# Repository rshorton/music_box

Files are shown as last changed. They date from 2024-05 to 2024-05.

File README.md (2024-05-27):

# Music Box

This project implements a simple music player using an Arduino and a dedicated mp3 player module.  The motivation was to create a simple nightstand player for my granddaughter.

See this video for a demo of the player:  https://youtu.be/NVYOizomKiI

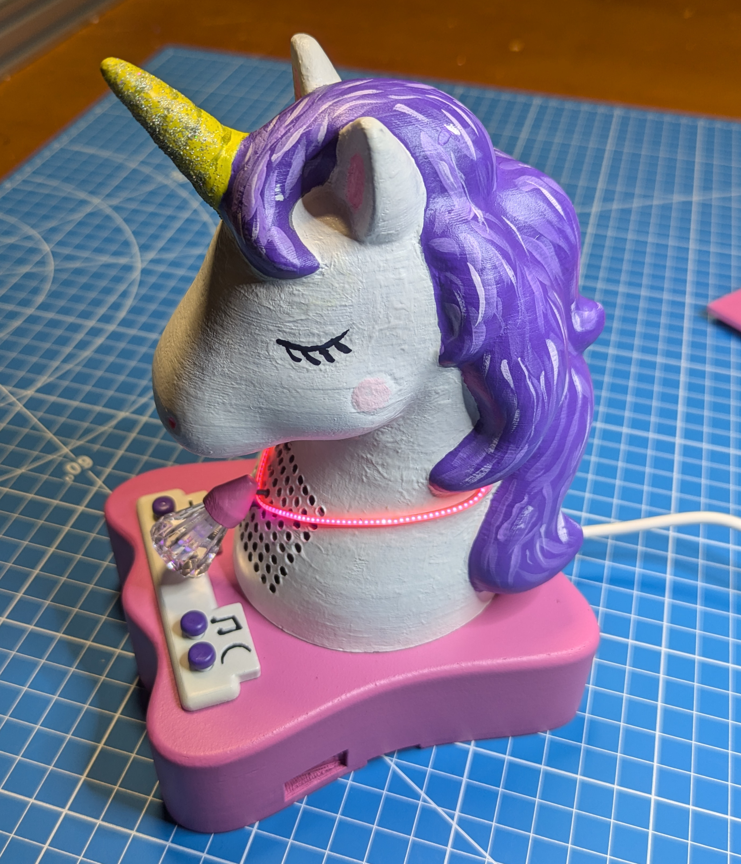
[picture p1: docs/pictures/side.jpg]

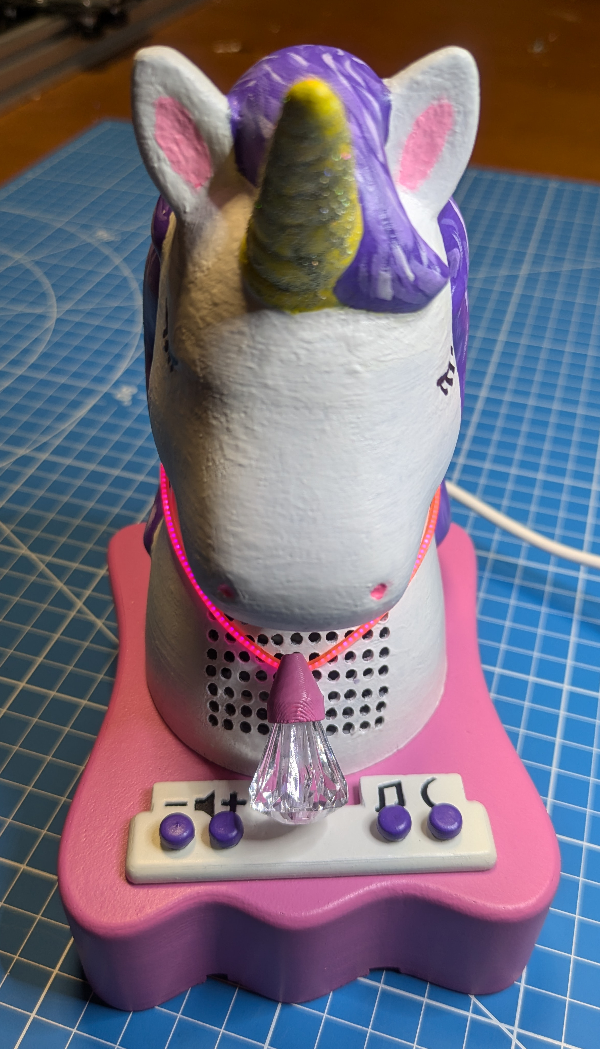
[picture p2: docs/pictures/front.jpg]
<br>
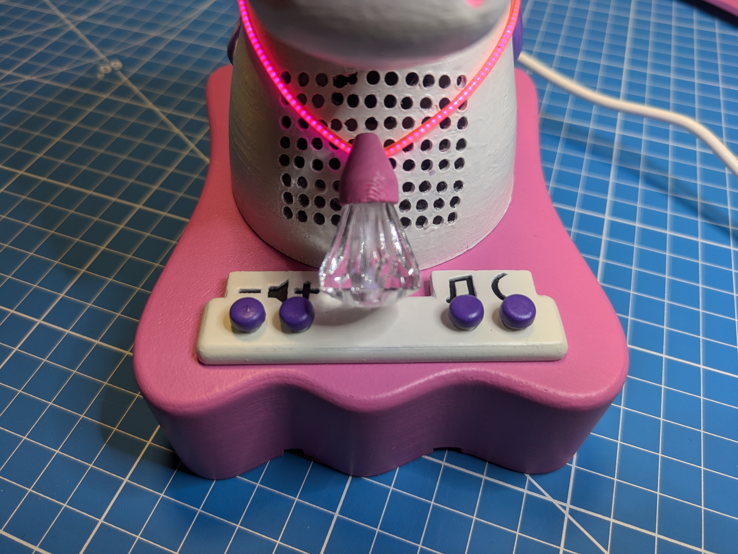
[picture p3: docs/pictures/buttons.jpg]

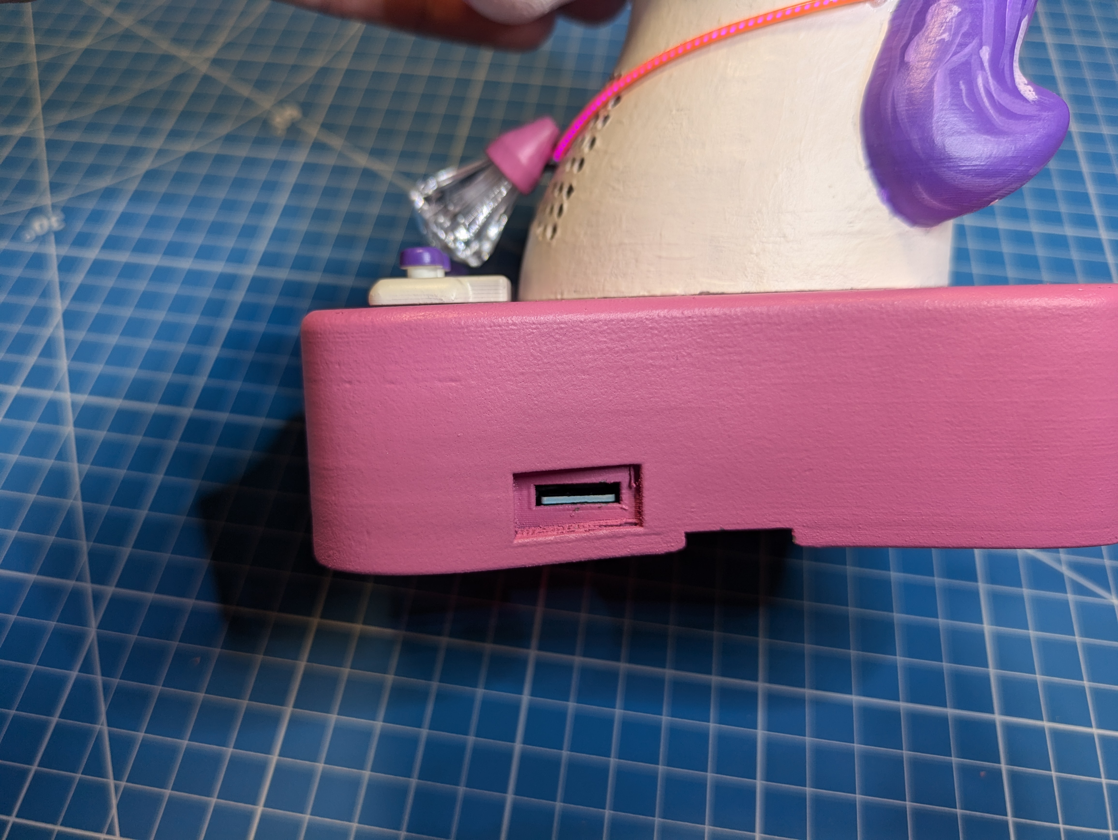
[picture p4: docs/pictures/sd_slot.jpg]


## Circuit

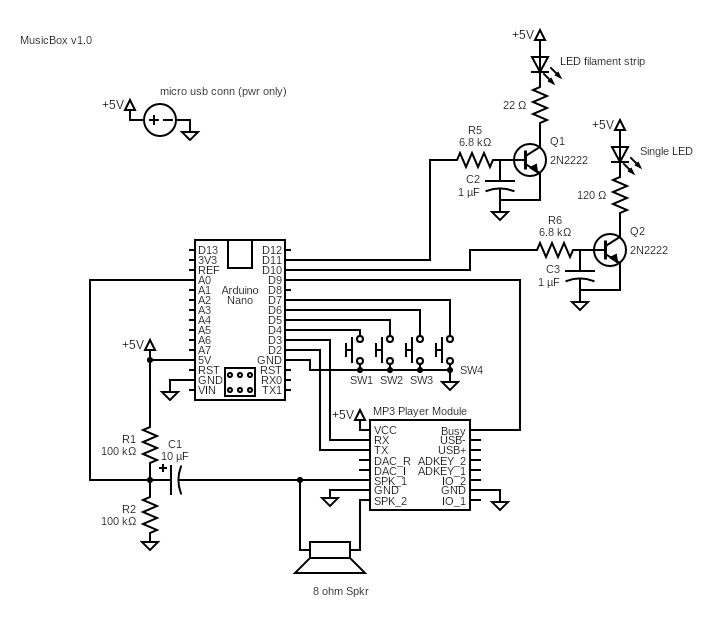
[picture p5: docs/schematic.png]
schematic

<br>
(Drawn using https://www.circuit-diagram.org)

The design uses a dedicated MP3 player module purchased from Amazon for this project plus other on-hand components including an Arduino Nano.  Key functionality:

 * MP3 player module with SD card slot - music is loaded on the SD card (see below).  The program running on the Arduino uses the serial interface of the player to control which mp3 file is played and to control the volume level.  Important: This player module has the same pin-out as the DFPlayer device, but its functionality is not exactly the same.  Credit goes to the various folks who provided an Amazon review of the device and provided clues to using it especially user "Richard Makes Escape Rooms".  The product link is https://www.amazon.com/dp/B07Y2YKYRS?ref=ppx_yo2ov_dt_b_product_details&th=1.  See player.cpp/hpp for the implementation.

 * Arduino Nano - The code of this repo runs on this device.  You could use just about any Arduino or micro for this function.  The program monitors the switch inputs and controls the player module accordingly.  It also flashes the LEDs in either a default 'breathing' mode while not playing where the LED intensity is varied up/down, or flashes based on the audio sound envelope.  Credit to Damian Peckett, https://projecthub.arduino.cc/mamifero/arduino-beat-detector-881c72, for his envelope detector filter that was encapsulated in filter.cpp/hpp.
 
 Other components:

 * 8 ohm 3W 2" speaker
 * Flexible LED filament strip from Adafruit (https://www.adafruit.com/product/5509)
 * Transistor circuits for driving the LEDs
 * Micro-usb adapter for providing power (no signals) to allow a 5v wall wart power supply to be used, https://www.amazon.com/gp/product/B07W844N43/ref=ppx_yo_dt_b_search_asin_title?ie=UTF8&psc=1
 * Reused an old 5v (1A) wall wart supply with micro-usb connector
 * Prototyping PCB board
 * SD card

 

## Software Functionality

Since the music box was designed for a young child, the goal was to make it simple.  As such it uses 4 keys:

* Vol+, Vol-
* One key for music play/next/pause. Press to start playing, short-press to skip to next, and long-press to pause. 
* Message playback - For my implementation these are 'goodnight' messages from the grandparents to our granddaughter.

To add a bit of whimsy, the program also supports some 'easter-egg' audio key-press modes.  Pressing any two-key combination at the same time will play one of several audio clips.  I have it play some silly sound effects such as a cow mooing, fart sound, etc.

For eye candy the LEDs are flashed to the music or in a 'breathing' mode when not playing.

### SD Card Contents

MP3 files for the songs/sound effects where prepared by recording the output of my phone into my laptop using Audacity.  Since the output of the music box is mono and use a small speaker, quality wasn't a goal.  I recorded at the default setting of 44.1kHz and then exported to MP3.

The layout of the audio files is shown below.  Example files are contained in the sample_audio folder of this project that can be use to test.

<hr>

* root directory of SD card
  
  01
  
      This folder contains the music files that are played when the music button is pressed.  
  
  02
  
      This folder contains audio files that are played when then message button (moon symbol) is pressed.  

  03

      This folder contains 'easter-egg' audio files played as described above.
    
<hr>

  Naming convention for audio files

  Number them beginning with 001 for the first file without skipping any numbers.  For example: 
  
      001.mp3   002.mp3 ...   010.mp3
  
  You can optionally append an underscore and then a description such as
  
      001_name of song.mp3

## Enclosure

Since my granddaughter likes unicorns, I chose to use a unicorn as the main design element.  I found a very nice unicorn STL on Thingiverse.

Unicorn Head
by kaloth licensed under the Creative Commons Attribution license.
https://www.thingiverse.com/thing:4920810/files

I printed the unicorn as large as my 3D printer supported and then designed a base using Fusion 360 to support it and hold the PCB for the circuit.

### Design notes

#### Unicorn Head

After printing with PLA, I used a knife and cut out enough material to insert the 2" speaker inside.  I also drilled holes to allow the sound to be better heard (I used a 3D-printed jig for that.).

#### Base

The base has a mounting support for the micro-usb PCB power connector, mounting supports for the main circuit board, and a slot on the side to allow the SD card to be removed after assembly.  I used threaded inserts for mounting the PCBs to the supports.

The top of the base has a slot onto which the button panel inserts.  I chose to use a separately-printed button panel with holes for the buttons since I wasn't sure exactly how many keys were going to be used intially.  That choice also allowed the button function to be designed as a relief in the button panel.  When painting the parts, I tried to paint the relief areas but found it was hard to have clean-looking edges for the resessed areas.  As such, I re-designed the button panel to use cut-outs for the function symbols and resessed areas on the bottom under the symbols where a separately printed piece could be first painted and then inserted to provide the background color.

#### Necklace

The flexible LED strip from Adafruit provides a nice finishing touch to the unicorn.  I also attached a plastic 'jewel' onto the filament.  The jewel has a LED inserted into it.  (The jewel was the initial inspiration for the entire project.)

#### Painting

I'm not an artsy person, so the finishing task was new territory for me.  However, with YouTube by your side you can learn and do almost anything. To smooth out the plastic layers before painting, I used thin layers of 'Bondo glazing & spot putty' and sanded between layers. I used acrylic paint and small brushes for the unicorn head and button tops, and spray paint for most everything else.  I used a clear poly spray coat over everything.

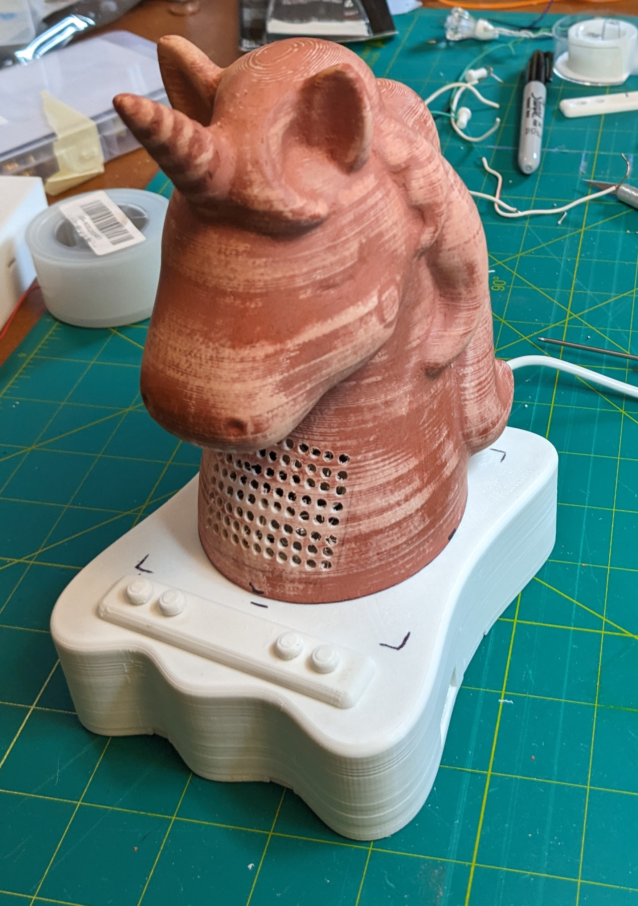
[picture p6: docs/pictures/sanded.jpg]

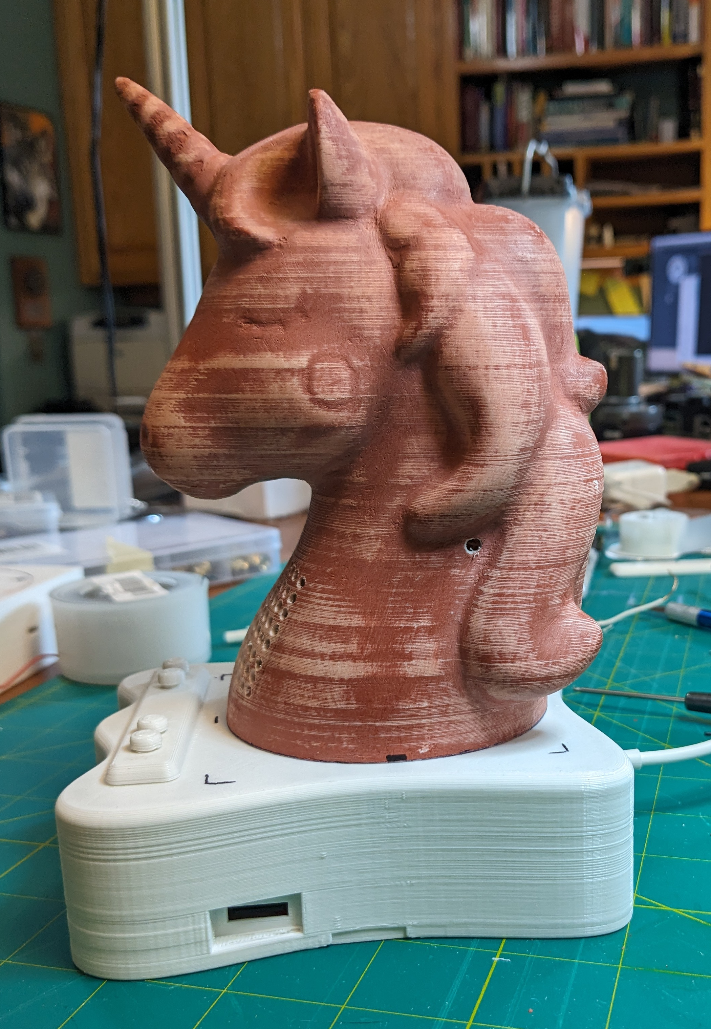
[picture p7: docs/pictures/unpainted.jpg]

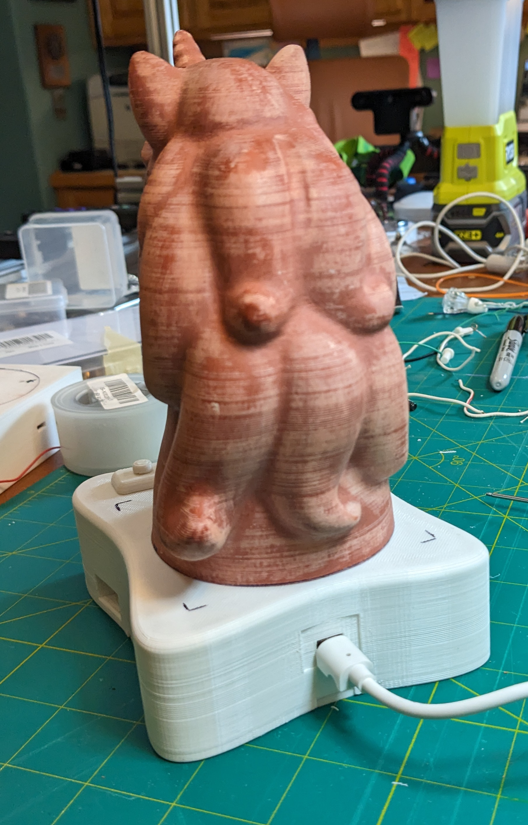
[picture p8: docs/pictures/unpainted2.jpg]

<hr>
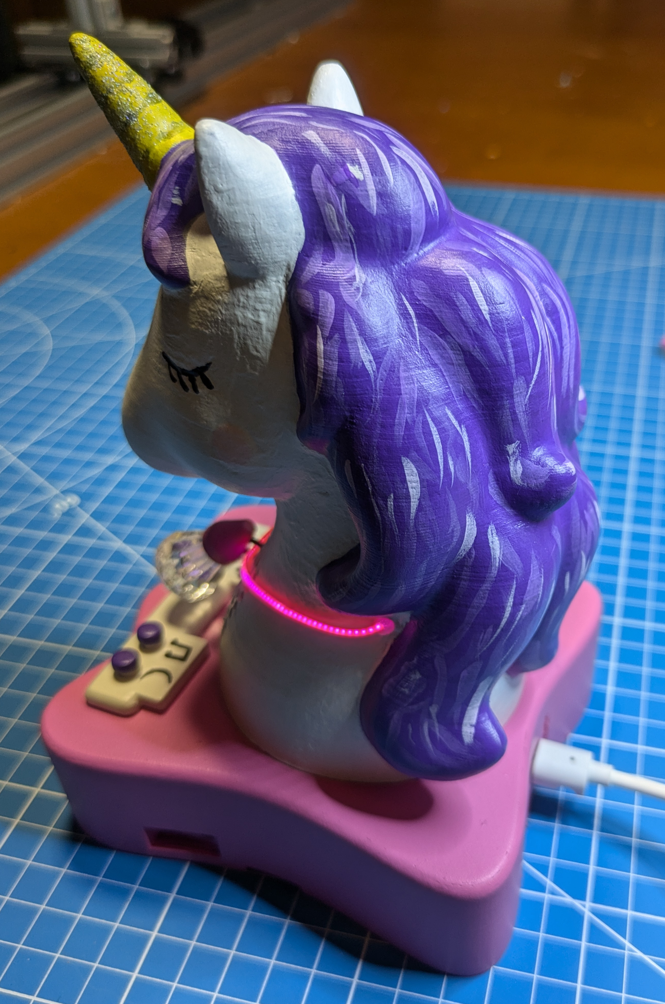
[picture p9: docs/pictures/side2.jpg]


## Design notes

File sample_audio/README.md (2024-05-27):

# Sample audio

The audio in this folder can be used to test the functionality of the music box. Copy the folders contained in this folder to a fat32-formatted SD card.  The contents of the SD card should look like this:

<root directory>
  01

      001.mp3
      002.mp3
      ...
      005.mp3

  02  
  
      001.mp3
      002.mp3
      ...
      005.mp3

  03

      001.mp3
      002.mp3
      ...
      006.mp3

Optionally, if you provide clip 007.mp3 in folder 03, that clip will be played when power is applied to the music box.

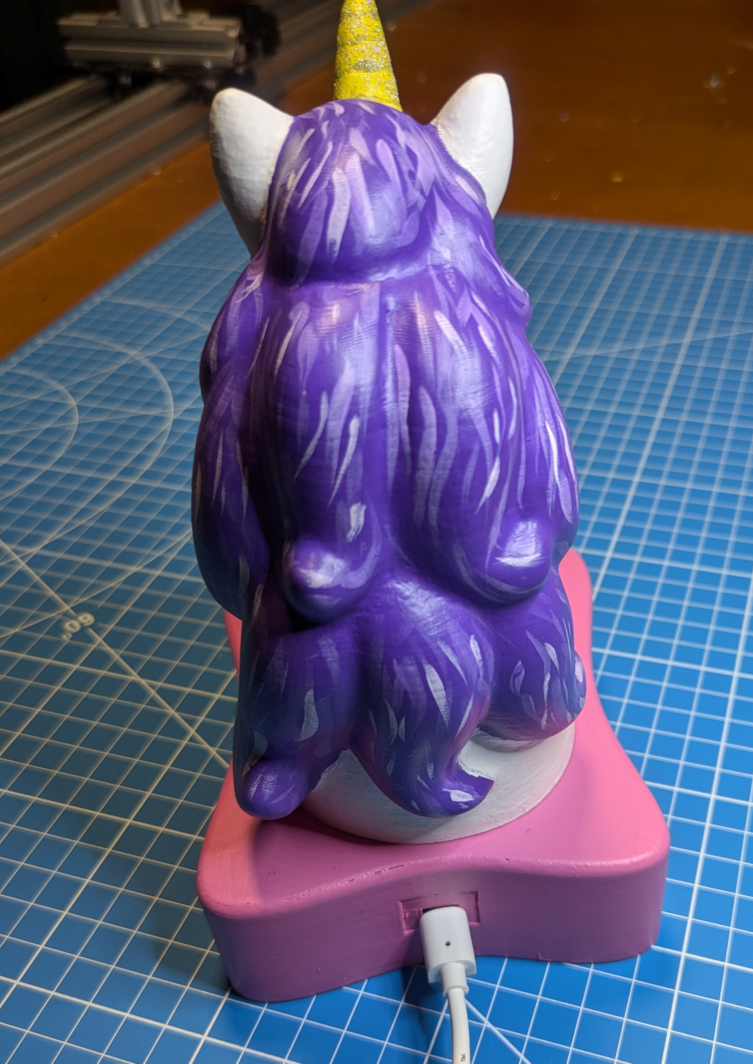
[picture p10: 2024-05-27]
docs/pictures/back.jpg

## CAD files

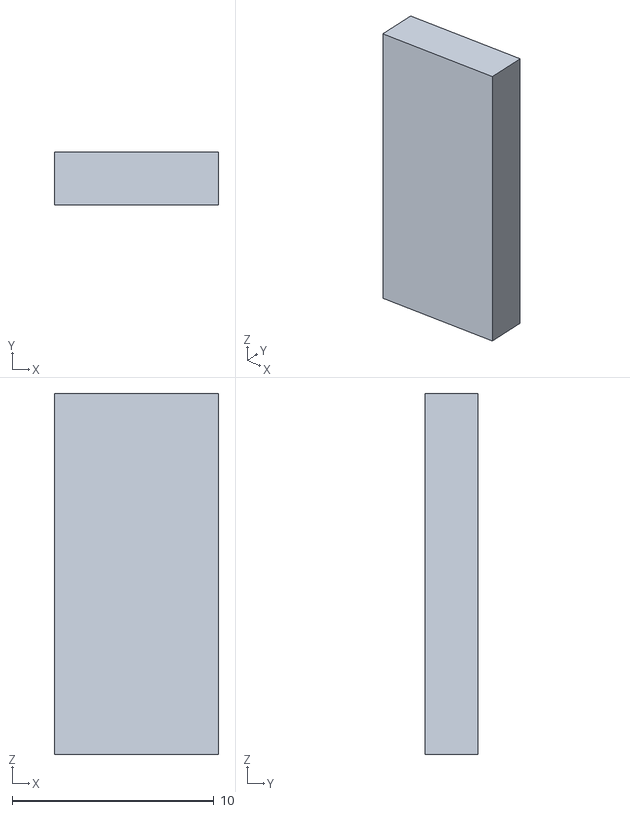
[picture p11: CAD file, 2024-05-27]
stl/filler1.stl
8.15 x 2.65 x 17.9

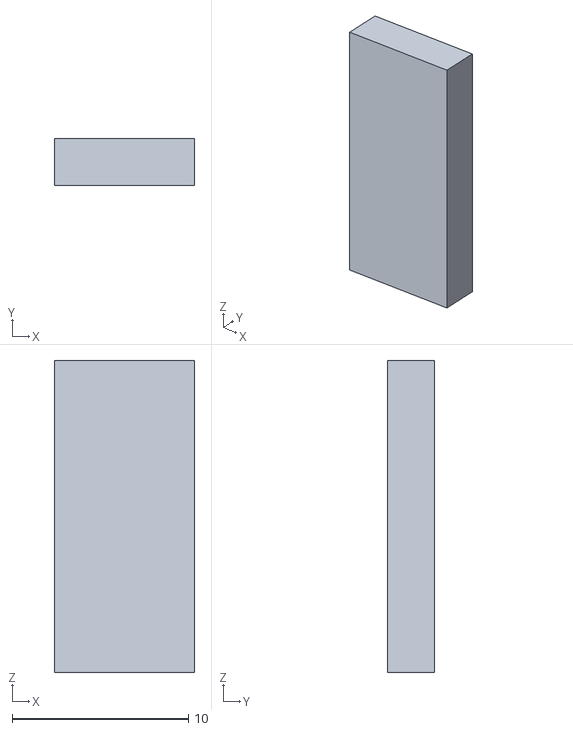
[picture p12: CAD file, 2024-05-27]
stl/filler2.stl
7.95 x 2.65 x 17.7

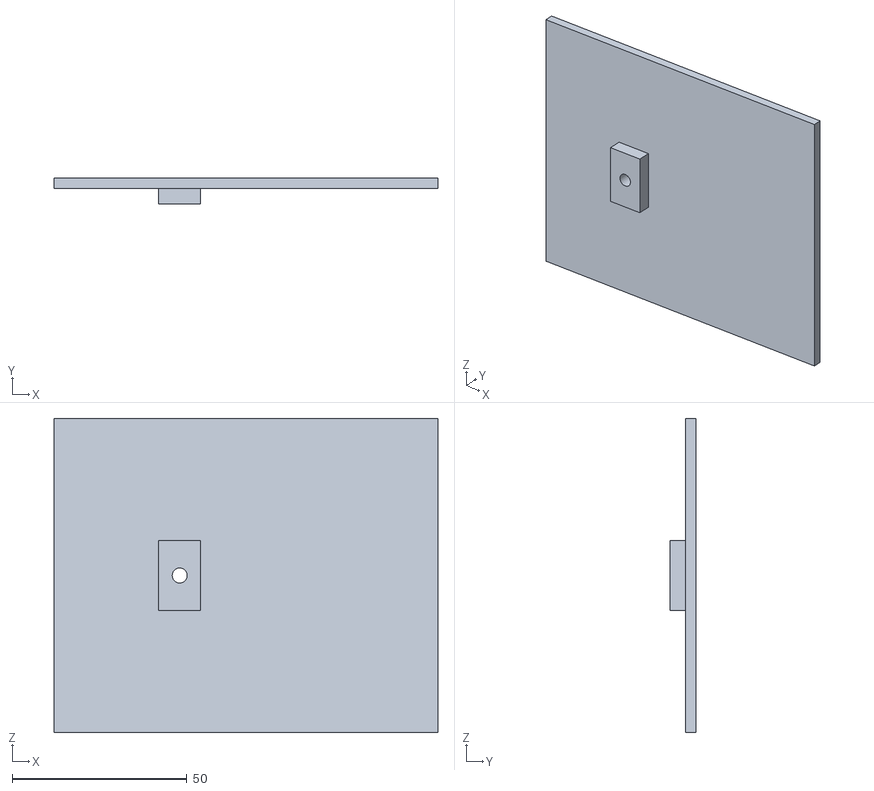
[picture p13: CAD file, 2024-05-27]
stl/base_lid.stl
110.0 x 7.50 x 90.0

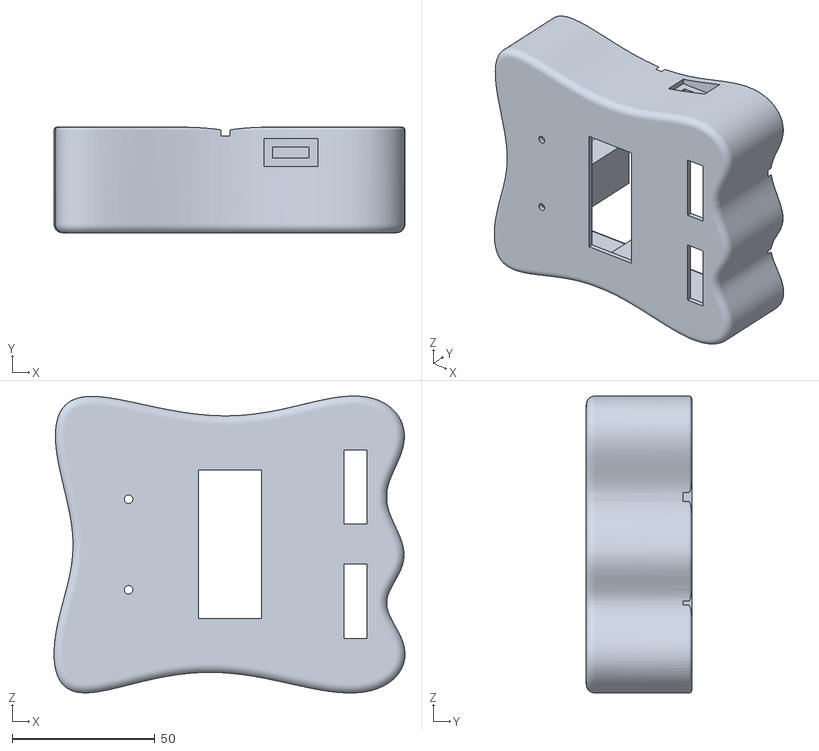
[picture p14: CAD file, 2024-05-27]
stl/base.stl
123.0 x 37.0 x 104.1

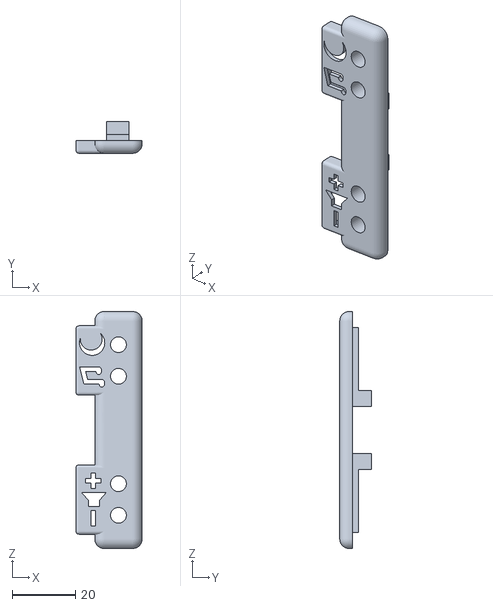
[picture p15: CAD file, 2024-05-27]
stl/button_panel.stl
21.0 x 10.0 x 75.0

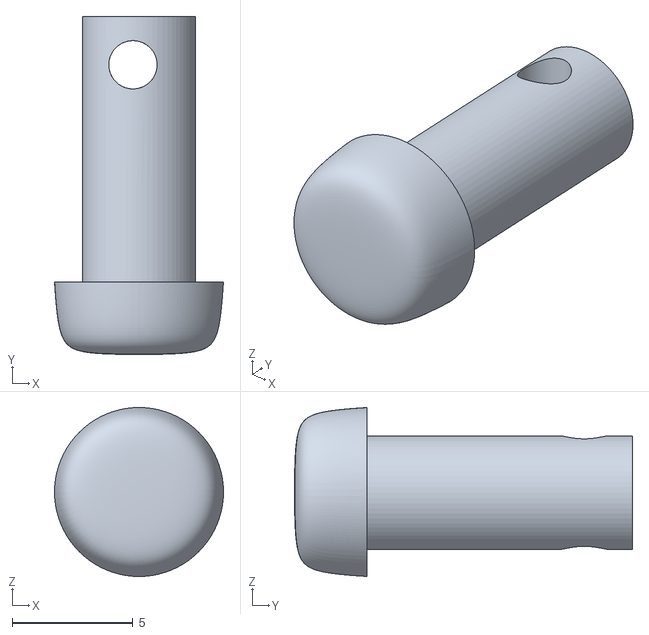
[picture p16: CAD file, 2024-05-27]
stl/button.stl
7.00 x 14.0 x 7.00

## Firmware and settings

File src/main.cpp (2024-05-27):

// MIT License
//
// Copyright (c) 2024 Scott Horton
// 
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
#include <Arduino.h>
#include "music_box.hpp"

const int PIN_SW_INPUT_VOL_MINUS = 7; // SW4
const int PIN_SW_INPUT_VOL_PLUS = 6;  // SW3
const int PIN_SW_INPUT_MUSIC = 4;     // SW1
const int PIN_SW_INPUT_SLEEP = 5;     // SW2

const int PIN_LED_OUT0 = 10;          // Drives single LED
const int PIN_LED_OUT1 = 11;          // Drives LED strip

const int PIN_PLAYER_RX = 2;          // From player module
const int PIN_PLAYER_TX = 3;          // To player modules
const int PIN_PLAYER_BUSY_INPUT = 9;  // Logic lo when player is playing

const int PIN_AUDIO_IN = 0;           // Audio input for beat detector
const float AUDIO_THRESH = 100.0f;    // Beat thresh

const int PIN_ANALOG_UNCONN = 1;      // Used for seeding Random


void setup()
{
  Serial.begin(9600);                 // Only used for console debugging
  Serial.println("ready");

  randomSeed(analogRead(PIN_ANALOG_UNCONN));

  MusicBox music_box(PIN_PLAYER_RX, PIN_PLAYER_TX, PIN_PLAYER_BUSY_INPUT,
                     PIN_SW_INPUT_MUSIC, PIN_SW_INPUT_SLEEP,
                     PIN_SW_INPUT_VOL_MINUS, PIN_SW_INPUT_VOL_PLUS,
                     PIN_LED_OUT0, PIN_LED_OUT1,
                     PIN_AUDIO_IN, AUDIO_THRESH);

  while (1) {
    music_box.update();
  }
}

void loop()
{
}

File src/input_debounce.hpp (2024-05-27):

// MIT License
//
// Copyright (c) 2024 Scott Horton
// 
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
#ifndef _INPUT_DEBOUNCE_HPP_
#define _INPUT_DEBOUNCE_HPP_

#include <Arduino.h>

/*
  This class is adapted from this Arduino sample code...

  Debounce

  Each time the input pin goes from LOW to HIGH (e.g. because of a push-button
  press), the output pin is toggled from LOW to HIGH or HIGH to LOW. There's a
  minimum delay between toggles to debounce the circuit (i.e. to ignore noise).

  The circuit:
  - LED attached from pin 13 to ground through 220 ohm resistor
  - pushbutton attached from pin 2 to +5V
  - 10 kilohm resistor attached from pin 2 to ground

  - Note: On most Arduino boards, there is already an LED on the board connected
    to pin 13, so you don't need any extra components for this example.

  created 21 Nov 2006
  by David A. Mellis
  modified 30 Aug 2011
  by Limor Fried
  modified 28 Dec 2012
  by Mike Walters
  modified 30 Aug 2016
  by Arturo Guadalupi

  This example code is in the public domain.

  https://www.arduino.cc/en/Tutorial/BuiltInExamples/Debounce
*/


class InputDebounce
{
public:
    InputDebounce() = default;    
    InputDebounce(int input_pin, bool use_pullup, unsigned long debounce_delay_ms);
    
    int update();

    int read() {
      return digitalRead(input_pin_);
    }

    int get_state() const {
        return button_state_;
    };

    void set_state(int state) {
        button_state_ = HIGH;
    };

    unsigned long get_state_duration() const {
      return  millis() - last_state_start_time_;
    }

    void drop_next_change(bool drop) {
      drop_next_change_ = drop;
    }

private:
    int input_pin_ = 0;
    unsigned long debounce_delay_ms_ = 50;    // the debounce time in ms

    int button_state_ = HIGH;                   // the current reading from the input pin
    int last_button_state_ = LOW;               // the previous reading from the input pin
    unsigned long last_debounce_time_ = 0;      // the last time the output pin was toggled
    unsigned long last_state_start_time_ = 0;   // the start time of the last button state
    bool drop_next_change_ = false;             // True to ignore next state change
};

#endif // _INPUT_DEBOUNCE_HPP_
